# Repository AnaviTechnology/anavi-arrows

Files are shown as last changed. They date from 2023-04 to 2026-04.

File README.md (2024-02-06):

# ANAVI Arrows

**Open source programmable keypad with 4 mechanical switches and a rotary encoder.**

ANAVI Arrows is an open source, custom-programmable, mini keyboard/keypad.

ANAVI Arrows has been designed with [the cross platform and open source electronics design automation suite KiCad](https://kicad.org/).

# License

The project is released under the [Creative Commons Attribution-ShareAlike 4.0 International (CC BY-SA 4.0)](https://creativecommons.org/licenses/by-sa/4.0/).

Note: This is a human-readable summary of (and not a substitute for) the [license](https://creativecommons.org/licenses/by-sa/4.0/legalcode).

You are free to:

Share — copy and redistribute the material in any medium or format Adapt — remix, transform, and build upon the material for any purpose, even commercially. The licensor cannot revoke these freedoms as long as you follow the license terms. Under the following terms:

Attribution — You must give appropriate credit, provide a link to the license, and indicate if changes were made. You may do so in any reasonable manner, but not in any way that suggests the licensor endorses you or your use. ShareAlike — If you remix, transform, or build upon the material, you must distribute your contributions under the same license as the original. No additional restrictions — You may not apply legal terms or technological measures that legally restrict others from doing anything the license permits. Notices:

You do not have to comply with the license for elements of the material in the public domain or where your use is permitted by an applicable exception or limitation. No warranties are given. The license may not give you all of the permissions necessary for your intended use. For example, other rights such as publicity, privacy, or moral rights may limit how you use the material.

You will have to provide a link to the original creator of the project http://www.anavi.technology on any documentation or website.

Credit can be attributed through a link to the creator website: http://www.anavi.technology

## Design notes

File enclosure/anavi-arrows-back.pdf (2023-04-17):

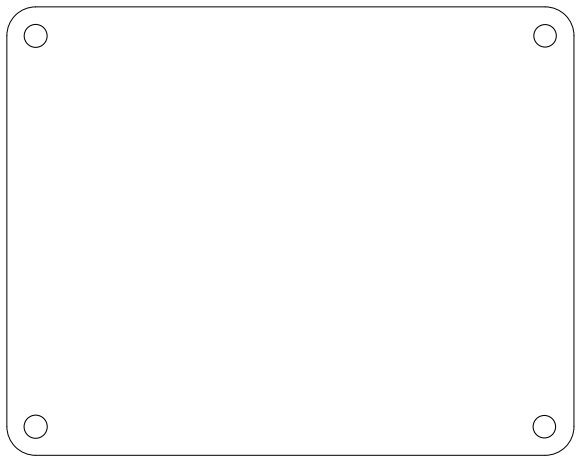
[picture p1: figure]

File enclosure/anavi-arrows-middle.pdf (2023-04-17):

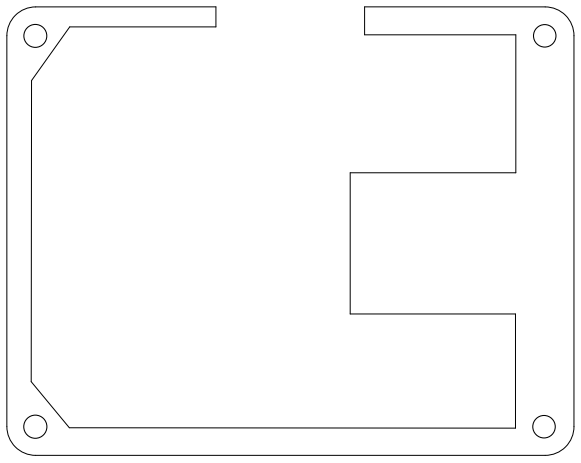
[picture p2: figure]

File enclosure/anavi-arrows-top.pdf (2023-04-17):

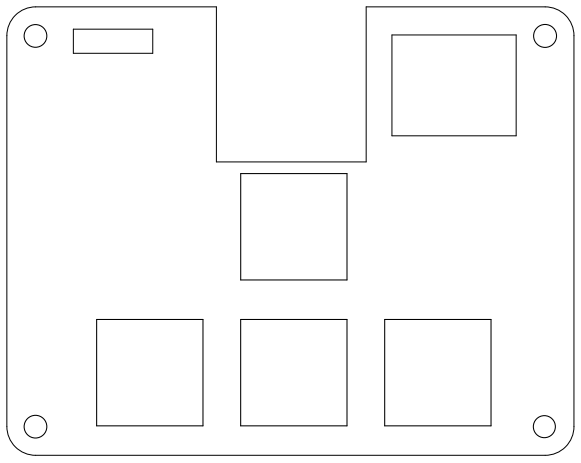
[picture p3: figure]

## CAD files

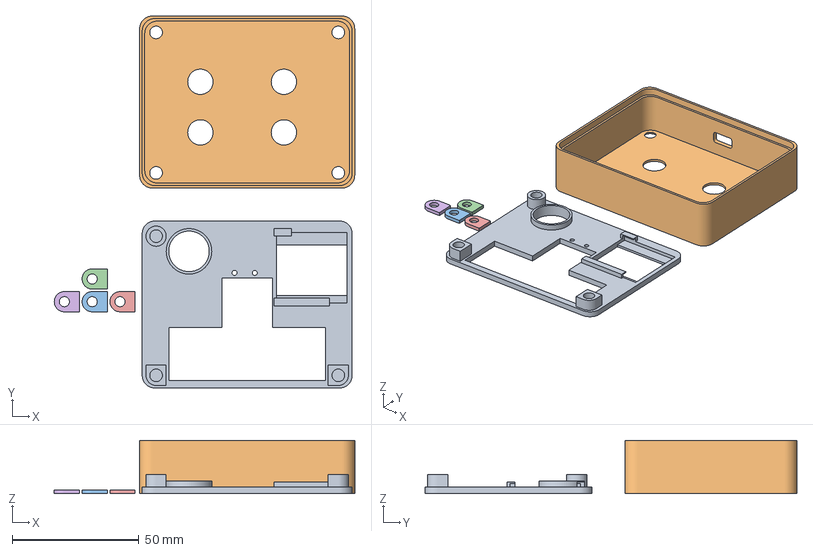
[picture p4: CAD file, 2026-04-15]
case/anavi-arrows.3mf
118.7 x 147.0 x 21.0 mm
anavi-arrows-top.stl
anavi-arrows-bottom.stl
keyboard-spacer.stl x 4

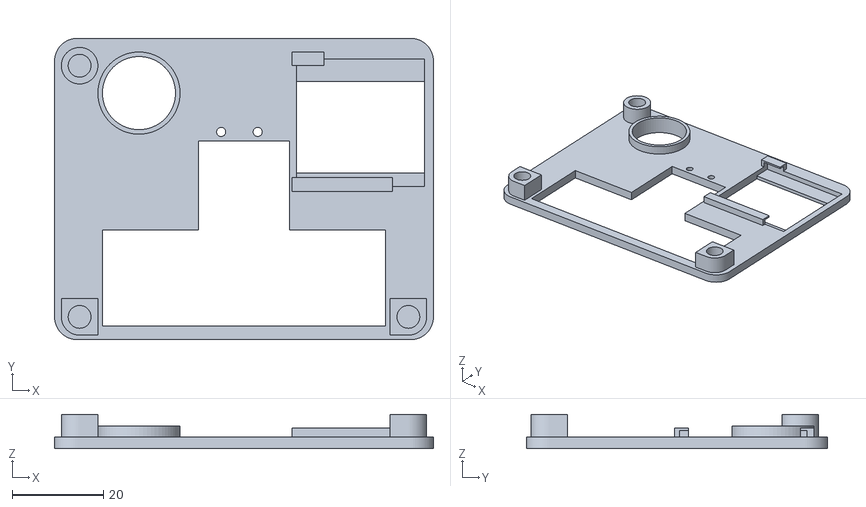
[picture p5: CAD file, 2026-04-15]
case/anavi-arrows-top.stl
83.0 x 66.0 x 7.50

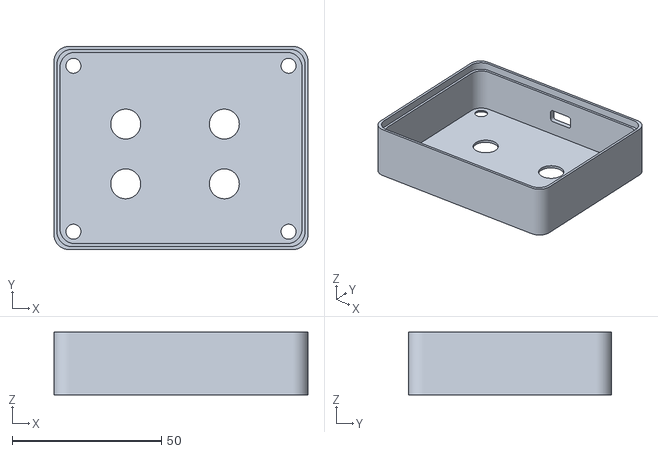
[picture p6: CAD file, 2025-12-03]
case/anavi-arrows-bottom.stl
85.0 x 68.0 x 21.0

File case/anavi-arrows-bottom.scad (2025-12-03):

// ========================
// Parameters
// ========================
corner_r = 5;    // PCB corner radius

wall_thickness = 2;  // Wall thickness
$fn = 64;              // smooth corners


// Case
// PCB + 5 mm
case_width = 80 + 5;
// PCB + 5 mm
case_lenght = 63 + 5; 
// May be it too much ... let's try with 22 next time
case_height = 21;

// Outer cylinder
outer_r = 3;
outer_h = 4;

// Inner hole
hole_r = 3;
hole_h = 2;

// USB-C connector
usbc_l = 10;
usbc_h = 5;

// LED
led_r = 5;

// WS2812B LED starting Y position
// 15
led_y = 17;
// WS2812B LED distance between rows
led_d = 20;

// increase for smoother cone ($fn)
segments = 64;

// ========================
// Case Top Module
// ========================
module case_top() {

    // Translate so inner PCB pocket starts at (0,0)
    translate([corner_r, corner_r, 0]) {
        difference() {
            // Outer shell (walls included)
            linear_extrude(height = case_height)
                rounded_rect(case_width,
                             case_lenght,
                             corner_r);

            // Main hollow interior
            // Make the base thinner, just 1 mm
            translate([wall_thickness, wall_thickness, 1])
                linear_extrude(height = case_height-3)
                    rounded_rect(case_width-2*wall_thickness, case_lenght-2*wall_thickness, corner_r);
            
            // Top hollow interior
            translate([wall_thickness/2, wall_thickness/2, case_height-3])
                linear_extrude(height = 3)
                    rounded_rect(case_width-wall_thickness, case_lenght-wall_thickness, corner_r);

            // Mounting hole 1 (top left)
            translate([1.5, case_lenght-2.5-hole_r*3, 0])
                // Cone
                cylinder(wall_thickness, hole_r, hole_h, center = false, $fn = segments);
            
            // Mounting hole 2 (top right)
            translate([case_width-3.5-hole_r*3+1, case_lenght-2.5-hole_r*3, 0])
                // Cone
                cylinder(wall_thickness, hole_r, hole_h, center = false, $fn = segments);

            // Mounting hole 3 (top right)
            translate([case_width-3.5-hole_r*3+1, 1, 0])
                // Cone
                cylinder(wall_thickness, hole_r, hole_h, center = false, $fn = segments);
            
            // Mounting hole 4 (bottom left)
            translate([1.5, 1, 0])
                // Cone
                cylinder(wall_thickness, hole_r, hole_h, center = false, $fn = segments);
                
            // WS2812B LEDs
            for (row = [0:1]) {
                row_position = led_y + row*led_d;
                // LED left
                translate([19, row_position, 0])
                    cylinder(h = wall_thickness, r = led_r, $fn = segments);
                // LED right
                translate([52, row_position, 0])
                    cylinder(h = wall_thickness, r = led_r, $fn = segments);
            }
                        
        }
    }
}

// ========================
// Rounded rectangle module
// ========================
module rounded_rect(x, y, radius) {
    minkowski() {
        square([x - 2*radius, y - 2*radius], center = false);
        circle(r = radius, $fn = $fn);
    }
}

// ========================
// Mounting hole
// ========================
module mounting_hole() {
    difference() {
        // Outer cylinder
        cylinder(h = outer_h, r = outer_r, $fn = 64);
        
        // Inner hole
        translate([0, 0, outer_h-hole_h])  // hole starts at base
            cylinder(h = hole_h, r = hole_r, $fn = 64);
    }
}

module usbc() {
    rotate([90,0,0])
        linear_extrude(height = wall_thickness)
            rounded_rect(usbc_l,usbc_h,1);
}

// ========================
// Top case
// ========================

difference() {
    // Main part of the case
    case_top();  
    // USB-C connector
    // -1 mm for the z position because of the thinner base
    translate([1+38, case_lenght, 7.8])
       usbc();
}

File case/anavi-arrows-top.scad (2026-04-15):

// ========================
// Parameters
// ========================
// PCB corner radius
corner_r = 5;    
// Wall thickness
wall_thickness = 2;  
// smooth corners
$fn = 64;              


// Case (2 mm shorter than the bottom, aka 1 mm on each side)
case_width = 83;
case_lenght = 66;
case_height = 2.5;

// Outer cylinder
outer_r = 4;
outer_h = 5;

// Inner hole
hole_r = 2.5;
hole_h = 4;

// Display size
display_size = 28;

// increase for smoother cone ($fn)
segments = 64;

// ========================
// Case Top Module
// ========================

module case_top() {
    difference() {
        
        // Translate so inner PCB pocket starts at (0,0)
        union() {
            
            translate([corner_r, corner_r, 0])
            // Outer shell (walls included)
            linear_extrude(height = case_height)
                rounded_rect(case_width,
                             case_lenght,
                             corner_r);
            
            // Rotary encoder border
            translate([9.5+9, 45+9, 0])
                cylinder(5, 9, 9, $fn = segments);

                        
            // Bottom left
            translate([1.5, 1, case_height])
                mounting_hole(true);
            
            // Bottom right
            translate([case_width-2*outer_r-1.5, 1, case_height])
                mounting_hole(false);
            
            // Top left
            translate([1.5, case_lenght-2*outer_r-2, case_height])
                mounting_hole_round();
            
            // No top right

            // Display holder bottom
            translate([case_width-1-2-display_size, case_lenght-5.5-display_size, case_height])
                cube([22, 3, 2]);
                
            // Display holder top
            translate([case_width-1-2-display_size, case_lenght-6, case_height])
                cube([7, 3, 2]);
        }
        
        // Display
        translate([case_width-2-display_size, case_lenght-4.5-display_size, 1])
            cube([display_size, display_size, 1.5]);
        translate([case_width-2-display_size, case_lenght-4.5-display_size+3, 0])
            cube([display_size, 20, 1]);
        // Cut the mounting element for the display
        translate([case_width-2-display_size, case_lenght-4.5-display_size, 1])
            cube([display_size, display_size, 3]);

                
        // Inner hollow segment of the keycaps
        // row with 3 keys
        translate([10.5, 3, 0])
            cube([62, 21, 30]);
        // row with the single key
        translate([10.5+21, 24, 0])
            cube([20, 19.5, 30]);

        // Opening for the rotary encoder
        translate([10.5+8, 46+8, 0])
            cylinder(10, 8, 8, $fn = segments);

        // Openings for the buttons
        
        // left
        translate([30.5+6, case_lenght-20.5, 0])
            cylinder(3, 1, 1, $fn = segments);
        
        // right
        translate([30.5+6+8, case_lenght-20.5, 0])
            cylinder(3, 1, 1, $fn = segments);
    }
    
}

// ========================
// Rounded rectangle module
// ========================
module rounded_rect(x, y, radius) {
    minkowski() {
        square([x - 2*radius, y - 2*radius], center = false);
        circle(r = radius, $fn = $fn);
    }
}

// ========================
// Mounting holes
// ========================
module mounting_hole_round() {
    // Position at start
    translate([outer_r, outer_r, 0]) {
        difference() {
            // Outer cylinder
            cylinder(h = outer_h, r = outer_r, $fn = segments);
            
            // Inner hole
            translate([0, 0, outer_h-hole_h])
                cylinder(h = hole_h, r = hole_r, $fn = segments);
        }
    }
}

module mounting_hole(left = true) {
    tr = left ? 0 : -outer_r;
    // Position at start
    translate([outer_r, outer_r, 0]) {
        difference() {
            
            union() {
                // Outer cylinder
                cylinder(h = outer_h, r = outer_r, $fn = segments);
                translate([tr, -outer_r, 0])
                    cube([4, 8, outer_h]);
                translate([-outer_r, 0, 0])
                    cube([8, 4, outer_h]);
            }
            
            // Inner hole
            translate([0, 0, outer_h-hole_h])
                cylinder(h = hole_h, r = hole_r, $fn = segments);
        }
    }
}

// ========================
// Top case
// ========================

case_top();

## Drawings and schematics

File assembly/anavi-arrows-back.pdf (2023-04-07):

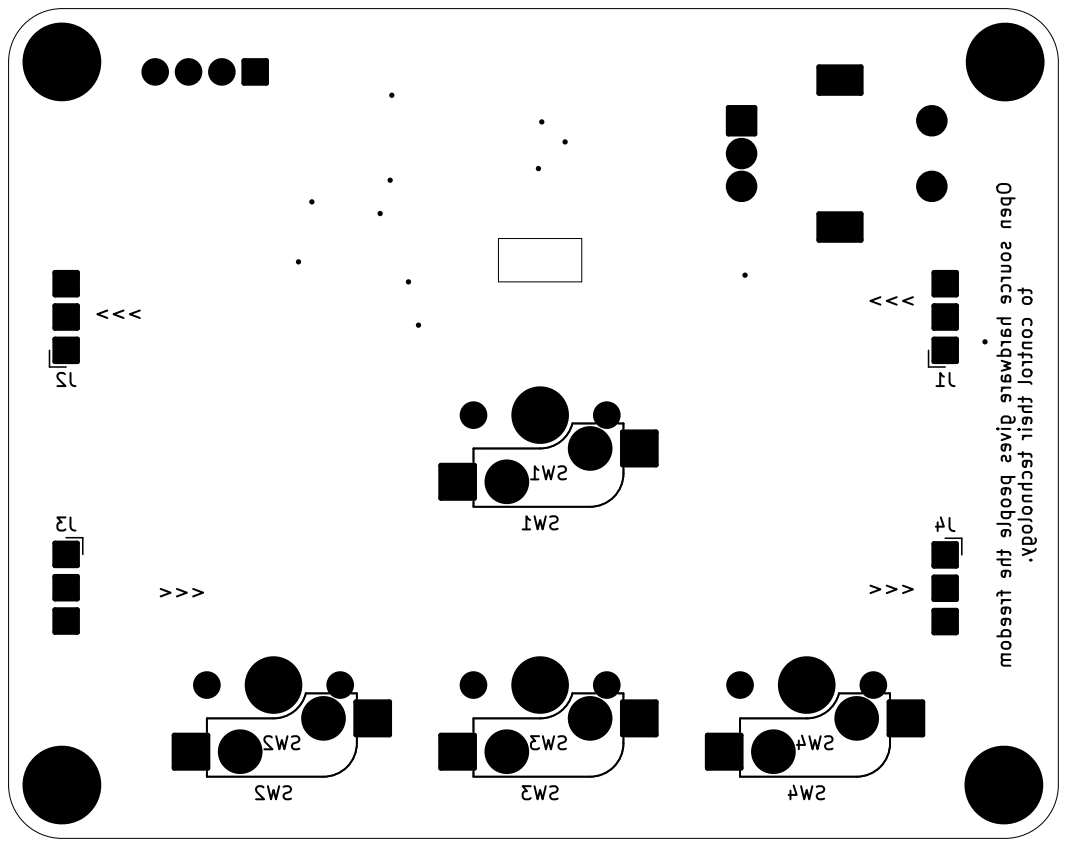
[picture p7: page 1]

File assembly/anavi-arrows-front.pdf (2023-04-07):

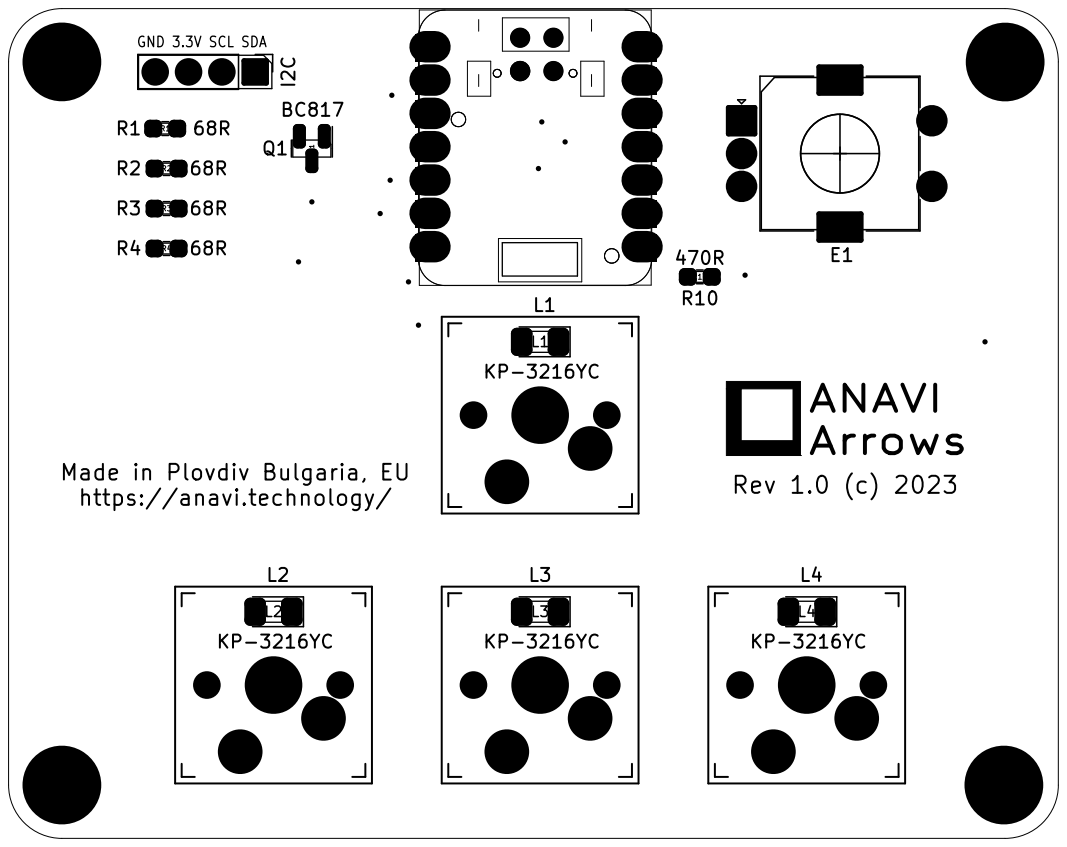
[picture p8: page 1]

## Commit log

2023-01-01 ANAVI Arrows
    Initial commit.
    [anavi-arrows.kicad_sch]
2023-01-02 anavi-arrows.kicad_pcb: Create PCB
    Create printed circuit board with 2 layers, components and hatched
    filled zones. Route traces on the front and the bottom layers.
2023-01-02 anavi-arrows.kicad_pcb: Update footprint
    Update the footprint of the module to leave a hole to the pads
    for connecting a battery.
2023-01-16 anavi-arrows.kicad_pcb: Add open source label
    Add a label on the back silkscreen about open source hardware.
2023-03-29 anavi-arrows.kicad_pcb: Add details
    Add project details.
2023-04-07 anavi-arrows.kicad_pcb: Fabrication notes
    Add details to help SMT assembly process.
2023-04-17 anavi-arrows: Enclosure
    Add top, middle and bottom plates for an enclosure.
2024-02-06 README.md: Fix KiCad URL
2025-12-03 case: Add design and STL files
    ANAVI Arrows case built with 2 parts, suitable for 3D print.
    Designed with the free and open source software OpenSCAD.
    [anavi-arrows-bottom.scad, anavi-arrows-bottom.stl, anavi-arrows-top.scad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]
2026-04-15 case: anavi-arrows-top: Change hole height
    Increase inner hole height from 2 to 4mm to simplify the process
    of placing brass threaded inserts with a special tool.
    [anavi-arrows-top.scad, anavi-arrows-top.stl]
2026-04-15 case/anavi-arrows.3mf: Add file
    Add 3D manufacturing format file for the case of ANAVI Arrows.
    [anavi-arrows.3mf]
